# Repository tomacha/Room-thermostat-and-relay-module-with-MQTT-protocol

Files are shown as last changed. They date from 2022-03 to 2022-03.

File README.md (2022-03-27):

# Room-thermostat-and-relay-module-with-MQTT-protocol

This project is a part of smart home system based on MQTT protocol for comunication. Thermostat is battery operated. To comunicate with relay module it uses Bluetooth Low Energy. Relay module comunicates by Wi-Fi with MQTT Broker. It also works as a gate between Broker and Thermostat.

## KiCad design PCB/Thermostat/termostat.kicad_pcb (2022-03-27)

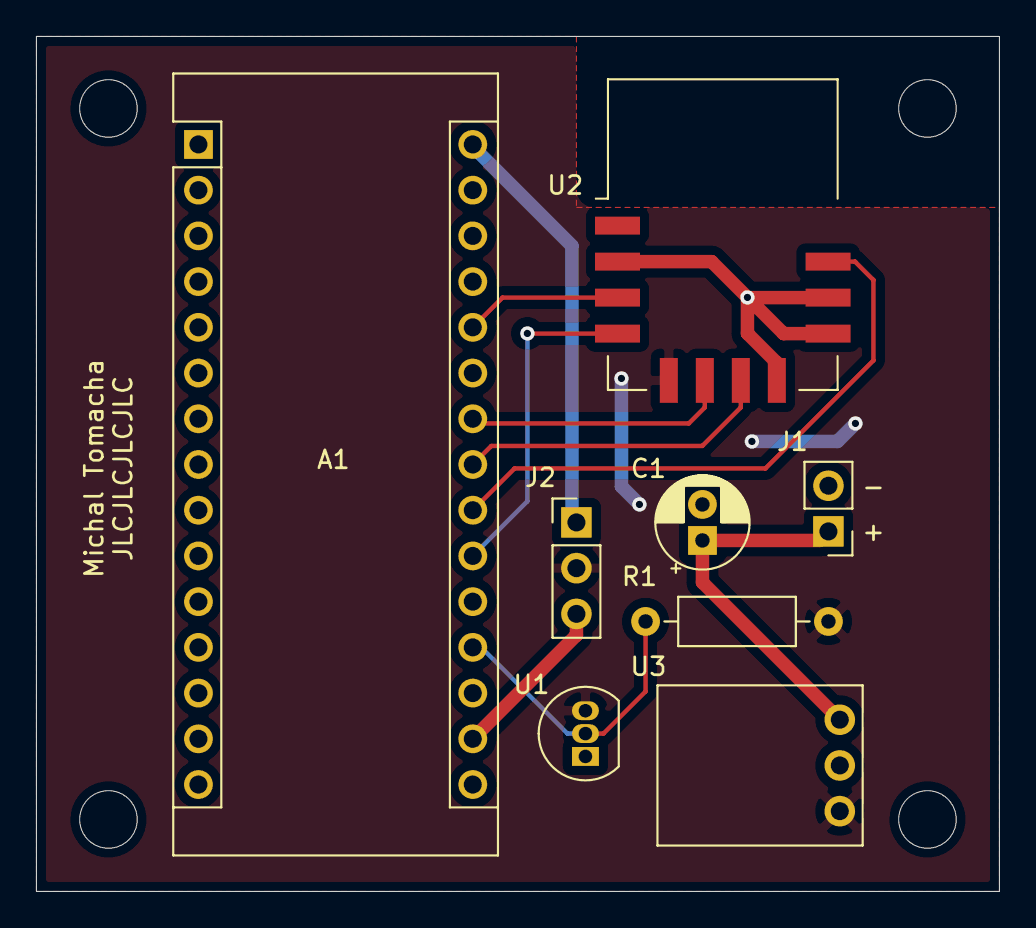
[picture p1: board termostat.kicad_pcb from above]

Board: 2 copper layers, 53.5 x 47.5 mm, 8 parts (0 on the bottom side), 11 nets.

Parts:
A1: STM32L432KC Nucleo-32; Arduino_Nano
C1: 33u; CP_Radial_D5.0mm_P2.00mm
J1: Batt Conn; PinHeader_1x02_P2.54mm_Vertical
J2: MC_PWR_SEL; PinHeader_1x03_P2.54mm_Vertical
R1: 4,7k; R_Axial_DIN0207_L6.3mm_D2.5mm_P10.16mm_Horizontal
U1: DS18B20; TO-92_Inline
U2: HM-BT4502
U3: U1V10F3

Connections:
3V3: A1.17, J2.3
+3V3: J2.2, R1.1, U1.3, U2.7, U3.1
+BATT: C1.1, J1.1, U3.3
DQ: A1.19, R1.2, U1.2
GND: A1.4, A1.29, C1.2, J1.2, U1.1, U2.2, U2.3, U2.4, U2.10, U3.2
INT: A1.22, U2.1
PDN: A1.23, U2.5
RXD: A1.21, U2.8
TXD: A1.26, U2.9
VIN: A1.30, J2.1
WAKEUP: A1.24, U2.6

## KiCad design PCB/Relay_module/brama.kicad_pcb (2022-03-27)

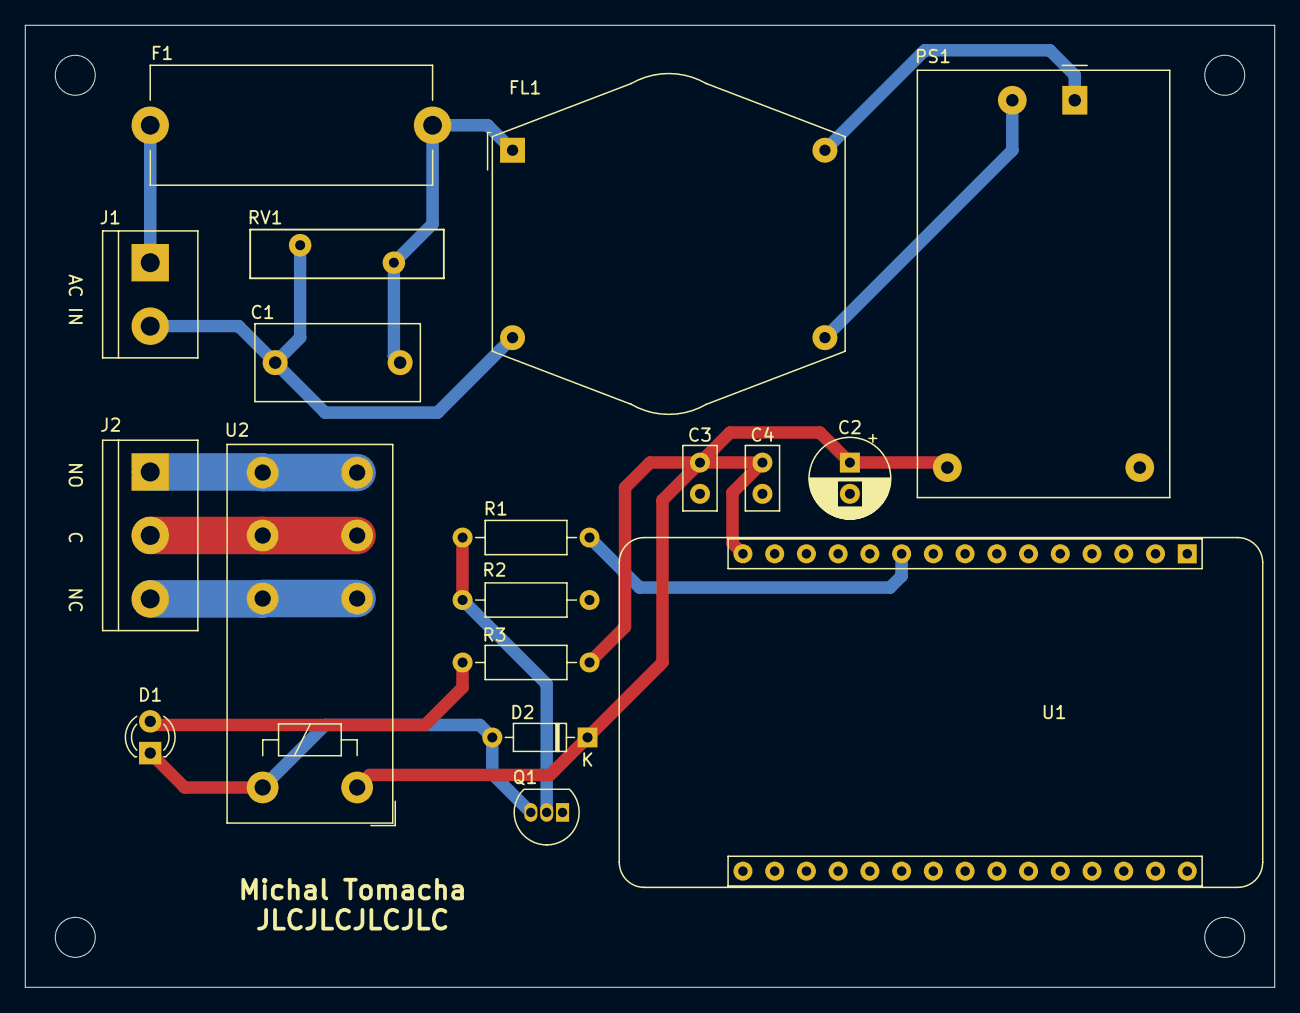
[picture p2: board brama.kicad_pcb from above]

Board: 2 copper layers, 100.0 x 77.0 mm, 18 parts (0 on the bottom side), 14 nets.

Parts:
C1: C; C_Rect_L13.0mm_W6.0mm_P10.00mm_FKS3_FKP3_MKS4
C2: CP; CP_Radial_D6.3mm_P2.50mm
C3, C4: C; C_Disc_D5.0mm_W2.5mm_P2.50mm
D1: LED; LED_D3.0mm
D2: D; D_DO-35_SOD27_P7.62mm_Horizontal
F1: Fuse; Fuseholder_Cylinder-5x20mm_Stelvio-Kontek_PTF78_Horizontal_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
FL1: EMI_Filter_CommonMode; Choke_Schaffner_RN122-04-28.0x27.0mm
J1: Screw_Terminal_01x02; TerminalBlock_bornier-2_P5.08mm
J2: Screw_Terminal_01x03; TerminalBlock_bornier-3_P5.08mm
PS1: HLK-PM01; Converter_ACDC_HiLink_HLK-PMxx
Q1: Q_NPN_EBC; TO-92_Inline
R1, R2, R3: R; R_Axial_DIN0207_L6.3mm_D2.5mm_P10.16mm_Horizontal
RV1: Varistor; RV_Disc_D15.5mm_W3.9mm_P7.5mm
U1: ESP32_DevKit_V1_DOIT; esp32_devkit_v1_doit
U2: MPI-S-105-C-3

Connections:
+5V: C2.1, C3.1, C4.1, D2.1, PS1.4, R3.1, U1.15, U2.2
GND: C2.2, C3.2, C4.2, PS1.3, Q1.1, R2.2, U1.14, U1.17
MCU: R1.1, U1.10
unnamed: C1.1, F1.2, FL1.1, RV1.1
unnamed: C1.2, FL1.3, J1.2, RV1.2
unnamed: D1.1, D2.2, Q1.3, U2.1
unnamed: D1.2, R3.2
unnamed: F1.1, J1.1
unnamed: FL1.2, PS1.1
unnamed: FL1.4, PS1.2
unnamed: J2.1, U2.5
unnamed: J2.2, U2.3
unnamed: J2.3, U2.4
unnamed: Q1.2, R1.2, R2.1

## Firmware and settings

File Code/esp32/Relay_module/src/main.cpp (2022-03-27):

#include <Arduino.h>

#include "BLEDevice.h"
#include "EspMQTTClient.h"
//#include "BLEScan.h"

#include <EEPROM.h>

#include <WiFi.h>
#include <ESPAsyncWebServer.h>
#include <AsyncTCP.h>
#include <esp_task_wdt.h>

uint32_t succes_count = 0;

AsyncWebServer server(80);

boolean websiteEnd = false;
boolean isInit = false;
boolean relay_on = false;
boolean temperature_received = false;

const char* ssid     = "Bridge config";
const char* password = "123456789";

String variable1 = "wifi_ssid"; 
String variable2 = "wifi_passwd"; 
String variable3 = "mqtt_ip"; 
String variable4 = "mqtt_login"; 
String variable5 = "mqtt_passwd"; 
String variable6 = "mqtt_name";

String wifi_ssid = ""; 
String wifi_passwd = ""; 
String mqtt_ip = ""; 
String mqtt_login = ""; 
String mqtt_passwd = ""; 
String mqtt_name = "";

const char index_html[] PROGMEM = R"rawliteral(
<!DOCTYPE HTML><html><head>
  <title>Bridge config</title>
  <meta name="viewport" content="width=device-width, initial-scale=1">
  </head><body>
  <form action="/get">
    Wi-Fi SSID: <input type="text" name="wifi_ssid"><br><br>
    Wi-Fi password: <input type="text" name="wifi_passwd"><br><br>
    MQTT broker IP: <input type="text" name="mqtt_ip"><br><br>
    MQTT login: <input type="text" name="mqtt_login"><br><br>
    MQTT password: <input type="text" name="mqtt_passwd"><br><br>
    MQTT client name: <input type="text" name="mqtt_name"><br><br>
    <input type="submit" value="Submit">
  </form>
</body></html>)rawliteral";

EspMQTTClient client;

// The remote service we wish to connect to.
static BLEUUID    serviceUUID("0000ffe0-0000-1000-8000-00805f9b34fb");
// The characteristics of the remote services we are interested in.
static BLEUUID    RxUUID("0000ffe4-0000-1000-8000-00805f9b34fb");
static BLEUUID    TxUUID("0000ffe9-0000-1000-8000-00805f9b34fb");

static boolean doConnectBLE = false; 
static boolean connectedBLE = false;
static boolean doScanBLE = true;

static BLERemoteCharacteristic* pRemoteCharacteristicNotify;
static BLERemoteCharacteristic* pRemoteCharacteristicWrite;
static BLEAdvertisedDevice* myDevice;

String mqtt_message;

float temperature;
float target_temp;
float temp_hist;

uint8_t relay_pin = 27;
uint8_t button_pin = 0; 

boolean reset_eeprom = false;


uint32_t button_start_time; 
uint32_t button_stop_time;

void IRAM_ATTR button_isr()
{
  if(digitalRead(0) == 0)
  {
    button_start_time = millis();
    relay_on = !relay_on;
  }
  else
  {
    button_stop_time = millis();
    if(button_stop_time - button_start_time >= 5000)
    {
      reset_eeprom = true;
    }
    button_start_time = 0;
    button_stop_time = 0;
  }
}

//website
void notFound(AsyncWebServerRequest *request) {
  request->send(404, "text/plain", "Not found");
}

void server_setup() {
  WiFi.mode(WIFI_AP);
  WiFi.softAP(ssid, password);

  Serial.println();
  Serial.print("IP Address: ");
  Serial.println(WiFi.softAPIP());

  server.on("/", HTTP_GET, [](AsyncWebServerRequest *request){
    request->send_P(200, "text/html", index_html);
  });

  server.on("/get", HTTP_GET, [] (AsyncWebServerRequest *request) {

    if (request->params() == 6) {
      wifi_ssid = request->getParam(variable1)->value();
      wifi_passwd = request->getParam(variable2)->value();
      mqtt_ip = request->getParam(variable3)->value();
      mqtt_login = request->getParam(variable4)->value();
      mqtt_passwd = request->getParam(variable5)->value();
      mqtt_name = request->getParam(variable6)->value();

      request->send(200, "text/html", "Data applied");
      delay(1000);
      server.end();
      WiFi.softAPdisconnect();
      websiteEnd = true;
    }
    else {
      request->send(200, "text/html", "Something went wrong.<br><a href=\"/\">Return to Home Page</a>");
    }

  });
  server.onNotFound(notFound);
  server.begin();
}
//website end

//MQTT
// This function is called once everything is connected (Wifi and MQTT)
// WARNING : YOU MUST IMPLEMENT IT IF YOU USE EspMQTTClient
void onConnectionEstablished()
{
  client.subscribe("Thermostat/Settings/TargetTemp", [](const String & payload) {
    target_temp = payload.toFloat();
  });

  client.subscribe("Thermostat/Settings/TempHist", [](const String & payload) {
    temp_hist = payload.toFloat();
  });
}
//MQTT end


//BLE
static void notifyCallback(BLERemoteCharacteristic* pBLERemoteCharacteristic, uint8_t* pData, size_t length, bool isNotify) {

    memcpy(&temperature, pData, length);
    
    if (client.isMqttConnected())
    {
      if (temperature < target_temp - temp_hist)
      {
        relay_on = true;
      }
      else if (temperature > target_temp + temp_hist)
      {
        relay_on = false;
      }
    }

    temperature_received = true;
}

class MyClientCallback : public BLEClientCallbacks {
  void onConnect(BLEClient* pclient) {
  }

  void onDisconnect(BLEClient* pclient) {
    connectedBLE = false;
    doScanBLE = true;
    Serial.println("Disconnected");
    
    mqtt_message = String(temperature, 1);

    delay(500);

    if (client.isMqttConnected())
    {
      if (temperature_received)
      {
        client.publish("Thermostat/Temperature", mqtt_message);
        if (relay_on)
        {
          client.publish("Thermostat/Relay", "ON");
        }
        else
        {
          client.publish("Thermostat/Relay", "OFF");
        }
      }
      temperature_received = false;
    }

    
    delay(2000);
  }
};

bool connectToServer() {
    esp_task_wdt_init(5000, true);
    esp_task_wdt_add(NULL);
    
    Serial.print("Forming a connection to ");
    Serial.println(myDevice->getAddress().toString().c_str());
    
    BLEClient*  pClient  = BLEDevice::createClient();
    Serial.println(" - Created client");

    pClient->setClientCallbacks(new MyClientCallback());

    // Connect to the remove BLE Server.
    if(!pClient->connect(myDevice))
    {
      Serial.println("Failed to connect");

      return false;
    }
    Serial.println(" - Connected to server");

    // Obtain a reference to the service we are after in the remote BLE server.
    BLERemoteService* pRemoteService = pClient->getService(serviceUUID);
    
    if (pRemoteService == nullptr) {
      Serial.print("Failed to find our service UUID: ");
      Serial.println(serviceUUID.toString().c_str());
      pClient->disconnect();
      
      return false;
    }
    Serial.println(" - Found our service");


    // Obtain a reference to the characteristic in the service of the remote BLE server.
    pRemoteCharacteristicNotify = pRemoteService->getCharacteristic(RxUUID);
    if (pRemoteCharacteristicNotify == nullptr) {
      Serial.print("Failed to find our characteristic UUID: ");
      Serial.println(RxUUID.toString().c_str());
      pClient->disconnect();
      
      return false;
    }
    Serial.println(" - Found Notify characteristic");

    // Read the value of the characteristic.
    if(pRemoteCharacteristicNotify->canRead()) {
      std::string value = pRemoteCharacteristicNotify->readValue();
      Serial.print("The notify characteristic value was: ");
      Serial.println(value.c_str());
    }

    if(pRemoteCharacteristicNotify->canNotify())
      pRemoteCharacteristicNotify->registerForNotify(notifyCallback);

    pRemoteCharacteristicWrite = pRemoteService->getCharacteristic(TxUUID);
    if (pRemoteCharacteristicWrite == nullptr) {
      Serial.print("Failed to find our characteristic UUID: ");
      Serial.println(TxUUID.toString().c_str());
      pClient->disconnect();
      
      return false;
    }
    Serial.println(" - Found Write characteristic");

    connectedBLE = true;
    
    esp_task_wdt_reset();
    return true;
}
/**
 * Scan for BLE servers and find the first one that advertises the service we are looking for.
 */
class MyAdvertisedDeviceCallbacks: public BLEAdvertisedDeviceCallbacks {
 /**
   * Called for each advertising BLE server.
   */
  void onResult(BLEAdvertisedDevice advertisedDevice) {
    
    if (advertisedDevice.getName() == "TempSens") {
      BLEDevice::getScan()->stop();
      doScanBLE = false;
      doConnectBLE = true;
      Serial.print("Found our BLE device: ");
      Serial.println(advertisedDevice.toString().c_str());
      myDevice = new BLEAdvertisedDevice(advertisedDevice);    
    } // Found our server
  } // onResult
}; // MyAdvertisedDeviceCallbacks
//BLE end

void setup() {
  uint8_t len;

  Serial.begin(115200);

  EEPROM.begin(122);

  pinMode(0, INPUT_PULLUP);
  attachInterrupt(0, button_isr, CHANGE);
  pinMode(relay_pin, OUTPUT);

  isInit = EEPROM.readBool(0);

  delay(500);

  Serial.println(isInit);

  if(!isInit)
  {
    len = 0;
    isInit = true;

    server_setup();

    while(!websiteEnd)
    {
      delay(1000);
    }

    len += EEPROM.writeBool(0, isInit); //1 byte
    len += EEPROM.writeString(len, wifi_ssid); //max 21 bytes
    len++;
    len += EEPROM.writeString(len, wifi_passwd); //max 21 bytes
    len++;
    len += EEPROM.writeString(len, mqtt_ip); //max 16 bytes
    len++;
    len += EEPROM.writeString(len, mqtt_login); //max 21 bytes
    len++;
    len += EEPROM.writeString(len, mqtt_passwd); //max 21 bytes
    len++;
    len += EEPROM.writeString(len, mqtt_name); //max 21 bytes

    EEPROM.commit();
  }
  else
  {
    len = 1;

    wifi_ssid = EEPROM.readString(len);
    len+=wifi_ssid.length();
    len++;
    wifi_passwd = EEPROM.readString(len);
    len+=wifi_passwd.length();
    len++;
    mqtt_ip = EEPROM.readString(len);
    len+=mqtt_ip.length();
    len++;
    mqtt_login = EEPROM.readString(len);
    len+=mqtt_login.length();
    len++;
    mqtt_passwd = EEPROM.readString(len);
    len+=mqtt_passwd.length();
    len++;
    mqtt_name = EEPROM.readString(len);
  }

  client.setMqttClientName(mqtt_name.c_str());
  client.setWifiCredentials(wifi_ssid.c_str(), "67070909316");
  //client.setWifiCredentials(wifi_ssid.c_str(), wifi_passwd.c_str());
  //client.setWifiCredentials(wifi_ssid.c_str(), "Yk5kwjfcHamh");
  //client.setWifiCredentials(wifi_ssid.c_str(), "j32Vfvubdkza");
  client.setMqttServer(mqtt_ip.c_str(), mqtt_login.c_str(), mqtt_passwd.c_str());

  //MQTT
  client.enableDebuggingMessages(); // Enable debugging messages sent to serial output
  client.enableHTTPWebUpdater(); // Enable the web updater. User and password default to values of MQTTUsername and MQTTPassword.
  client.setMqttReconnectionAttemptDelay(5000);
  //end MQTT

  //BLE
  BLEDevice::init("");

  // Retrieve a Scanner and set the callback we want to use to be informed when we
  // have detected a new device. Specify that we want active scanning. 
  BLEScan* pBLEScan = BLEDevice::getScan();
  pBLEScan->setAdvertisedDeviceCallbacks(new MyAdvertisedDeviceCallbacks());
  pBLEScan->setInterval(1349);
  pBLEScan->setWindow(449);
  pBLEScan->setActiveScan(true);
  //end BLE 
} // End of setup.

// This is the Arduino main loop function.
void loop() {
  client.loop();

  if (client.isMqttConnected())
  {
    if (doConnectBLE == true) {
      if (connectToServer()) {
        Serial.println("We are now connected to the BLE Server.");
        succes_count++;
        Serial.print("succes count: ");
        Serial.println(succes_count);
      } else {
        Serial.println("We have failed to connect to the server.");
        ESP.restart();
      }
      doConnectBLE = false;  
    }

    if(doScanBLE){
      delay(1000);
      Serial.println("Scan start");
      BLEDevice::getScan()->start(1);
    }
  }
  
  if(relay_on)
  {
    digitalWrite(relay_pin, HIGH);
  }
  else
  {
    digitalWrite(relay_pin, LOW);
  }

  if(reset_eeprom)
  {
    Serial.println("Button pressed for 5 sec. Resetting...");
    isInit = false;
    EEPROM.writeBool(0, isInit);
    EEPROM.commit();
    reset_eeprom = false;
    delay(1000);
    ESP.restart();
  }
} // End of loop

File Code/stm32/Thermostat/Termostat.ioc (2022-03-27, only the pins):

Mcu.UserName=STM32L432KCUx
PA0.GPIO_Label=DS18B20
PA0.Signal=GPIO_Output
PA2.Signal=LPUART1_TX
PA3.Signal=LPUART1_RX
PA4.GPIO_Label=INT
PA4.Signal=GPXTI4
PA5.GPIO_Label=PDN
PA5.Signal=GPIO_Output
PA6.GPIO_Label=WAKEUP
PA6.Signal=GPIO_Output

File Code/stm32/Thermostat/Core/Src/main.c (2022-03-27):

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
/* Includes ------------------------------------------------------------------*/
#include "main.h"
#include "usart.h"
#include "rtc.h"
#include "tim.h"
#include "gpio.h"

/* USER CODE BEGIN Includes */
#include "stdio.h"
#include "stdlib.h"
#include "string.h"
#include "hm_bt4502.h"
#include "ds18b20.h"
/* USER CODE END Includes */


/* USER CODE BEGIN PV */
BT4502_t BT4502 = {
		.INT_GPIO = INT_GPIO_Port,
		.INT_GPIO_Pin = INT_Pin,
		.PDN_GPIO = PDN_GPIO_Port,
		.PDN_GPIO_Pin = PDN_Pin,
		.WAKEUP_GPIO = WAKEUP_GPIO_Port,
		.WAKEUP_GPIO_Pin = WAKEUP_Pin,
		.huart = &hlpuart1,
		.recv_buf = {0},
		.state = BT4502_State_Uninitialized,
		.auth_code = "1234"};

uint8_t rtc_reset = 1;
uint8_t bt_not_connected_count = 0;
uint8_t test = 1;

extern Ds18b20Sensor_t	ds18b20[_DS18B20_MAX_SENSORS];
float temperature;
/* USER CODE END PV */

void SystemClock_Config(void);
/**
  * @brief  The application entry point.
  * @retval int
  */
int main(void)
{
  /* MCU Configuration--------------------------------------------------------*/

  /* Reset of all peripherals, Initializes the Flash interface and the Systick. */
  HAL_Init();

  /* Configure the system clock */
  SystemClock_Config();

  /* Initialize all configured peripherals */
  MX_RTC_Init();
  MX_GPIO_Init();
  MX_LPUART1_UART_Init();
  MX_TIM6_Init();
  /* USER CODE BEGIN 2 */
  BT4502_Init(&BT4502);
  if(!Ds18b20_Init())
  {
	  return -1;
  }
  /* USER CODE END 2 */

  /* Infinite loop */
  /* USER CODE BEGIN WHILE */
  while (1)
  {
    /* USER CODE END WHILE */

    /* USER CODE BEGIN 3 */

	Ds18b20_ManualConvert();

	if(BT4502.state == BT4502_State_Advertising)
	{
		bt_not_connected_count++;
		if(bt_not_connected_count == 2)
		{
			//BT4502_Sleep(&BT4502);
			BT4502.state = BT4502_State_Data_Sent;
		}
	}

	if(BT4502.state == BT4502_State_Data_Received)
	{
		//bt_not_connected_count = 0;
		if(strcmp((char *)BT4502.recv_buf, "TTM:CONNECT\r\n") == 0)
		{
			BT4502.state = BT4502_State_Connected;
		}
		else if(strcmp((char *)BT4502.recv_buf, "TTM:DISCONNECT\r\n") == 0)
		{
			if(BT4502.state != BT4502_State_Sleep)
			{
				BT4502.state = BT4502_State_Advertising;
			}
		}
		else if(strcmp((char *)BT4502.recv_buf, "TTM:DISCONNECT FOR TIMEOUT\r\n") == 0)
		{
			if(BT4502.state != BT4502_State_Sleep)
			{
				BT4502.state = BT4502_State_Advertising;
			}
		}
		memset(BT4502.recv_buf, '\0', sizeof(BT4502.recv_buf));
  	}

	if(BT4502.state == BT4502_State_Connected)
	{
		if(ds18b20[0].DataIsValid)
		{
			HAL_Delay(1000);
			BT4502_Send_Data(&BT4502, &ds18b20[0].Temperature, sizeof(ds18b20[0].Temperature));
			HAL_Delay(1000);
		}
		else
		{
			BT4502.state = BT4502_State_Data_Sent;
		}
  	}

	if(BT4502.state == BT4502_State_Data_Sent)
	{
		bt_not_connected_count = 0;
		BT4502_Sleep(&BT4502);
		HAL_RTCEx_DeactivateWakeUpTimer(&hrtc);
		rtc_reset = 1;
	}
	else if(BT4502.state == BT4502_State_Sleep)
	{
		BT4502_WakeUp(&BT4502);
	}

	if(rtc_reset == 1)
	{
		rtc_reset = 0;
		HAL_RTCEx_SetWakeUpTimer_IT(&hrtc, (10000-1), 32000/16); //10000-1 to 5s
	}
	HAL_SuspendTick();
	HAL_PWREx_EnterSTOP2Mode(PWR_STOPENTRY_WFI);
  }
  /* USER CODE END 3 */
}

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
/* USER CODE BEGIN 4 */
void HAL_GPIO_EXTI_Callback(uint16_t GPIO_Pin)
{
	SystemClock_Config();
	HAL_ResumeTick();

	if(GPIO_Pin == BT4502.INT_GPIO_Pin)
	{
		BT4502_INT_Pin_Callback(&BT4502);
	}
}

void HAL_RTCEx_WakeUpTimerEventCallback(RTC_HandleTypeDef *hrtc)
{
	SystemClock_Config();
	HAL_ResumeTick();

	HAL_RTCEx_DeactivateWakeUpTimer(hrtc);

	rtc_reset = 1;
}
/* USER CODE END 4 */
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


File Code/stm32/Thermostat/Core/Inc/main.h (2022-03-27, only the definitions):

#define DS18B20_Pin GPIO_PIN_0
#define DS18B20_GPIO_Port GPIOA
#define INT_Pin GPIO_PIN_4
#define INT_GPIO_Port GPIOA
#define INT_EXTI_IRQn EXTI4_IRQn
#define PDN_Pin GPIO_PIN_5
#define PDN_GPIO_Port GPIOA
#define WAKEUP_Pin GPIO_PIN_6
#define WAKEUP_GPIO_Port GPIOA

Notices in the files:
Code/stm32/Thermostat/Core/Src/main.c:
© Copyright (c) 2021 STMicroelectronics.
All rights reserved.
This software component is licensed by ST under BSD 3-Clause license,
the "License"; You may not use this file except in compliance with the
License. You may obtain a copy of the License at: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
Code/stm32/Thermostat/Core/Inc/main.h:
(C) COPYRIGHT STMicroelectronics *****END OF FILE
